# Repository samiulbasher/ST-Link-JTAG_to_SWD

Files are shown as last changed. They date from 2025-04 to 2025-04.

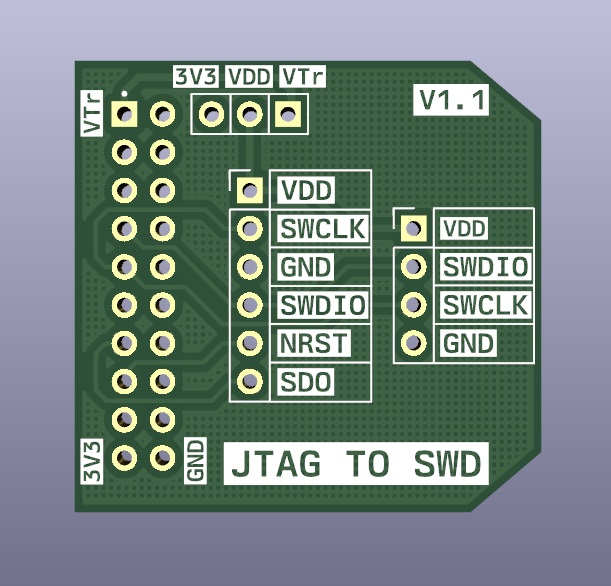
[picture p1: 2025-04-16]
JTAG_to_SWD/circuit/TOP.jpg

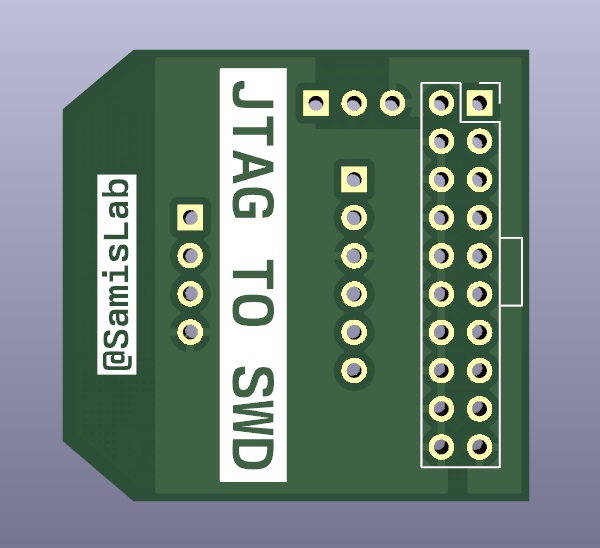
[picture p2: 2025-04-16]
JTAG_to_SWD/circuit/BOTTOM.jpg

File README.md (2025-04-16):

# ST-Link JTAG to SWD Adapter

A simple, compact adapter that converts a legacy ARM 20-pin JTAG/SWD IDC connector to a standard SWD header. Compatible with ST-Link, J-Link, and other JTAG-based programmers.

---

## 🧰 General

This adapter is designed for developers to **simplify the development and debugging process**.

Instead of dealing with messy jumper wires or complex breakout boards, this provides a clean and reliable solution for converting JTAG to SWD—ideal for use with:

- ST-Link  
- J-Link  
- Other generic JTAG programmers

---

## 📌 Features

- **Plug & Play** — No need to look up datasheets or pinouts  
- **Developer-Friendly** — Saves time and reduces frustration  
- **Labeled Pins** — Clear labeling right on the PCB  
- **Reduces Errors** — Focus on your work, not wiring  
- **Compact** — Just 30x31 mm in size (*2-layer PCB*)

---

## 🧾 Applications

- Debugging and programming ARM Cortex-M microcontrollers  
- Quick SWD access for STM32 and other ARM-based chips  
- Works with any 20-pin JTAG header programmer

---

## 📷 Board Images

> Photos of the adapter and panelized PCB:

ST-Link V2 JTAG to SWD Adapter  
ST-Link V3 JTAG to SWD Adapter  
Panelized Board
JTAG to SWD Adapter

---

## 📍 Pin Details

All pin names are printed directly on the PCB.  
Here's a reference for the minimum required connections:

- **4 Pins** (1, 2, 3, 4) — Programming only  
- **6 Pins** (1, 2, 3, 4, 5, 6) — Full debugging + programming

---

## 🔌 Jumper Connection

When using different ST-Link versions:

- **Genuine ST-Link V2 or V3**:  
  Connect `VTarget (VTr)` to `VDD` [target's mcu `VDD`].

- **Clone ST-Link (usually ST-Link V2, e.g., Chinese versions)**:  
  Connect `3V3` to `VDD` [target's mcu `VDD`].

---

## 📦 Specifications

| Attribute | Value |
|---|---|
| Dimensions | 30 mm x 31 mm |
| Connector Type | ARM 20-pin JTAG to SWD Header |
| Programmer Support | ST-Link, J-Link, and others |

---

## ✅ Compatibility

| Programmer | Compatible |
|---|---|
| ST-Link V2 | ✅ |
| ST-Link V3 | ✅ |
| J-Link | ✅ |
| Other JTAG headers | ✅ |

---

---

## 📁 Design Files & Gerber Files

- The `JTAG_to_SWD/` directory contains the original **KiCad project files**.  
  If you’d like to modify or customize the board, you can easily do so using KiCad.

- The `gerber/` directory includes **production-ready files** for PCB manufacturing.

  Inside it, you’ll find a `panel/V1.1/` subfolder — this contains the **panelized version** of the PCB (`JTAG_to_SWD_panel_V1.1.zip`).  
  This file is ready to upload directly to [JLCPCB](https://jlcpcb.com) for manufacturing.

💡 This is a **2-layer PCB**, and each panel contains **6 individual boards**.  
That means for just **$2**, you can get **30 PCBs** produced at JLCPCB!

---

## 📝 License

This project is released under the [MIT License](LICENSE).

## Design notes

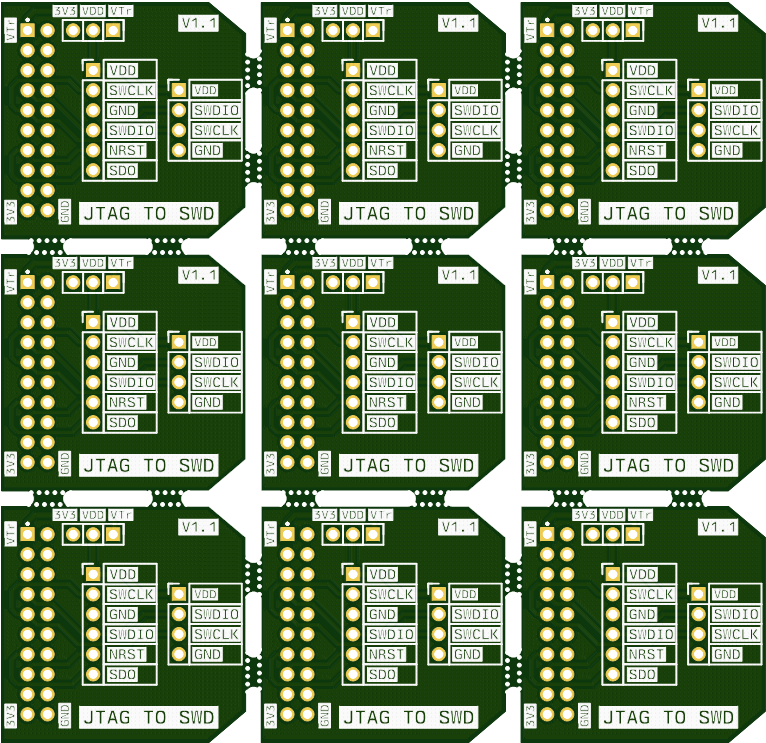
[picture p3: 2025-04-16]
JTAG_to_SWD/gerbers/panel/V1.1/JTAG_to_SWD_panel_V1.1_Combined_Top.png

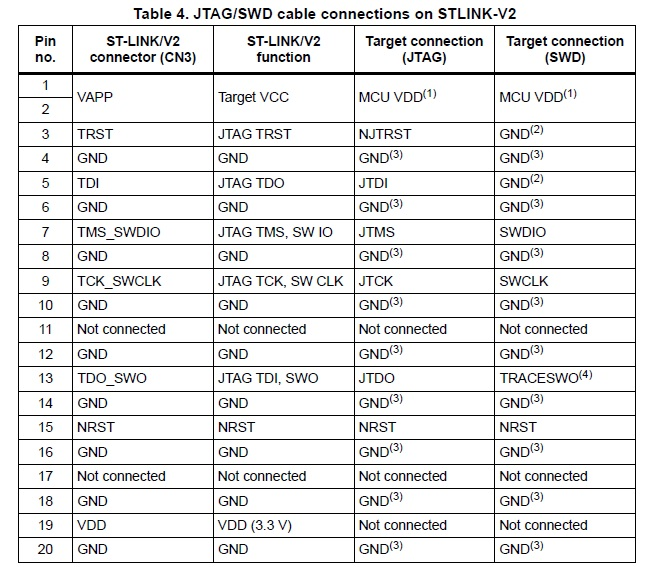
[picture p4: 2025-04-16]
utility/JTAG_STLINK-V2.png

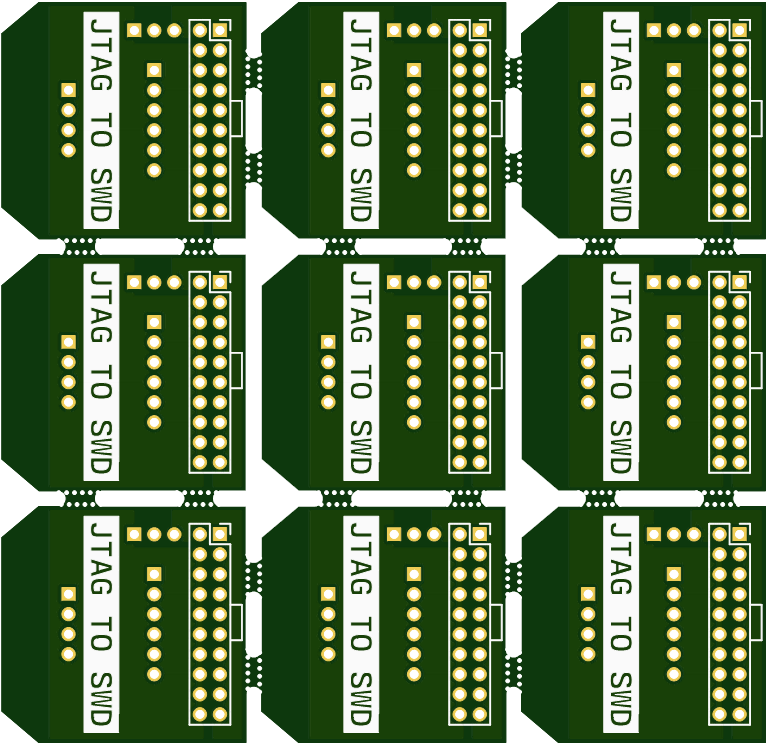
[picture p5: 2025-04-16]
JTAG_to_SWD/gerbers/panel/V1.1/JTAG_to_SWD_panel_V1.1_Combined_Bottom.png

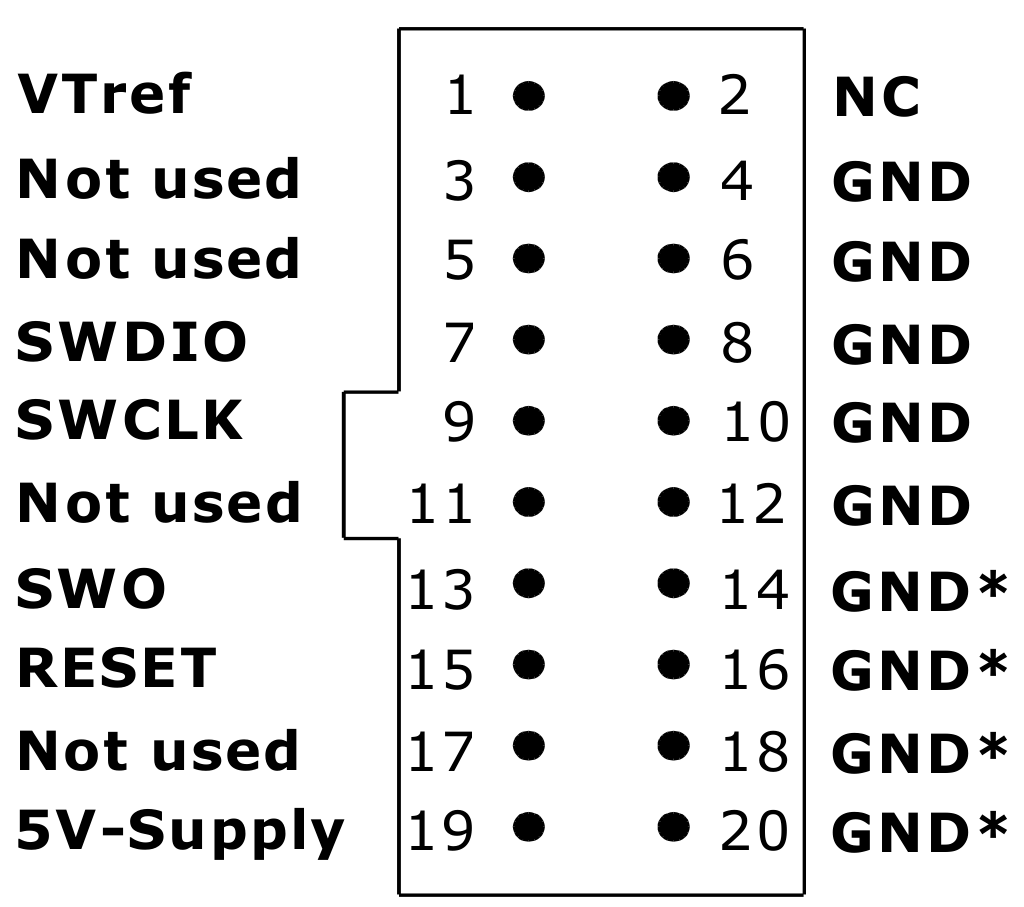
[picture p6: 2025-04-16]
utility/JTAG.png

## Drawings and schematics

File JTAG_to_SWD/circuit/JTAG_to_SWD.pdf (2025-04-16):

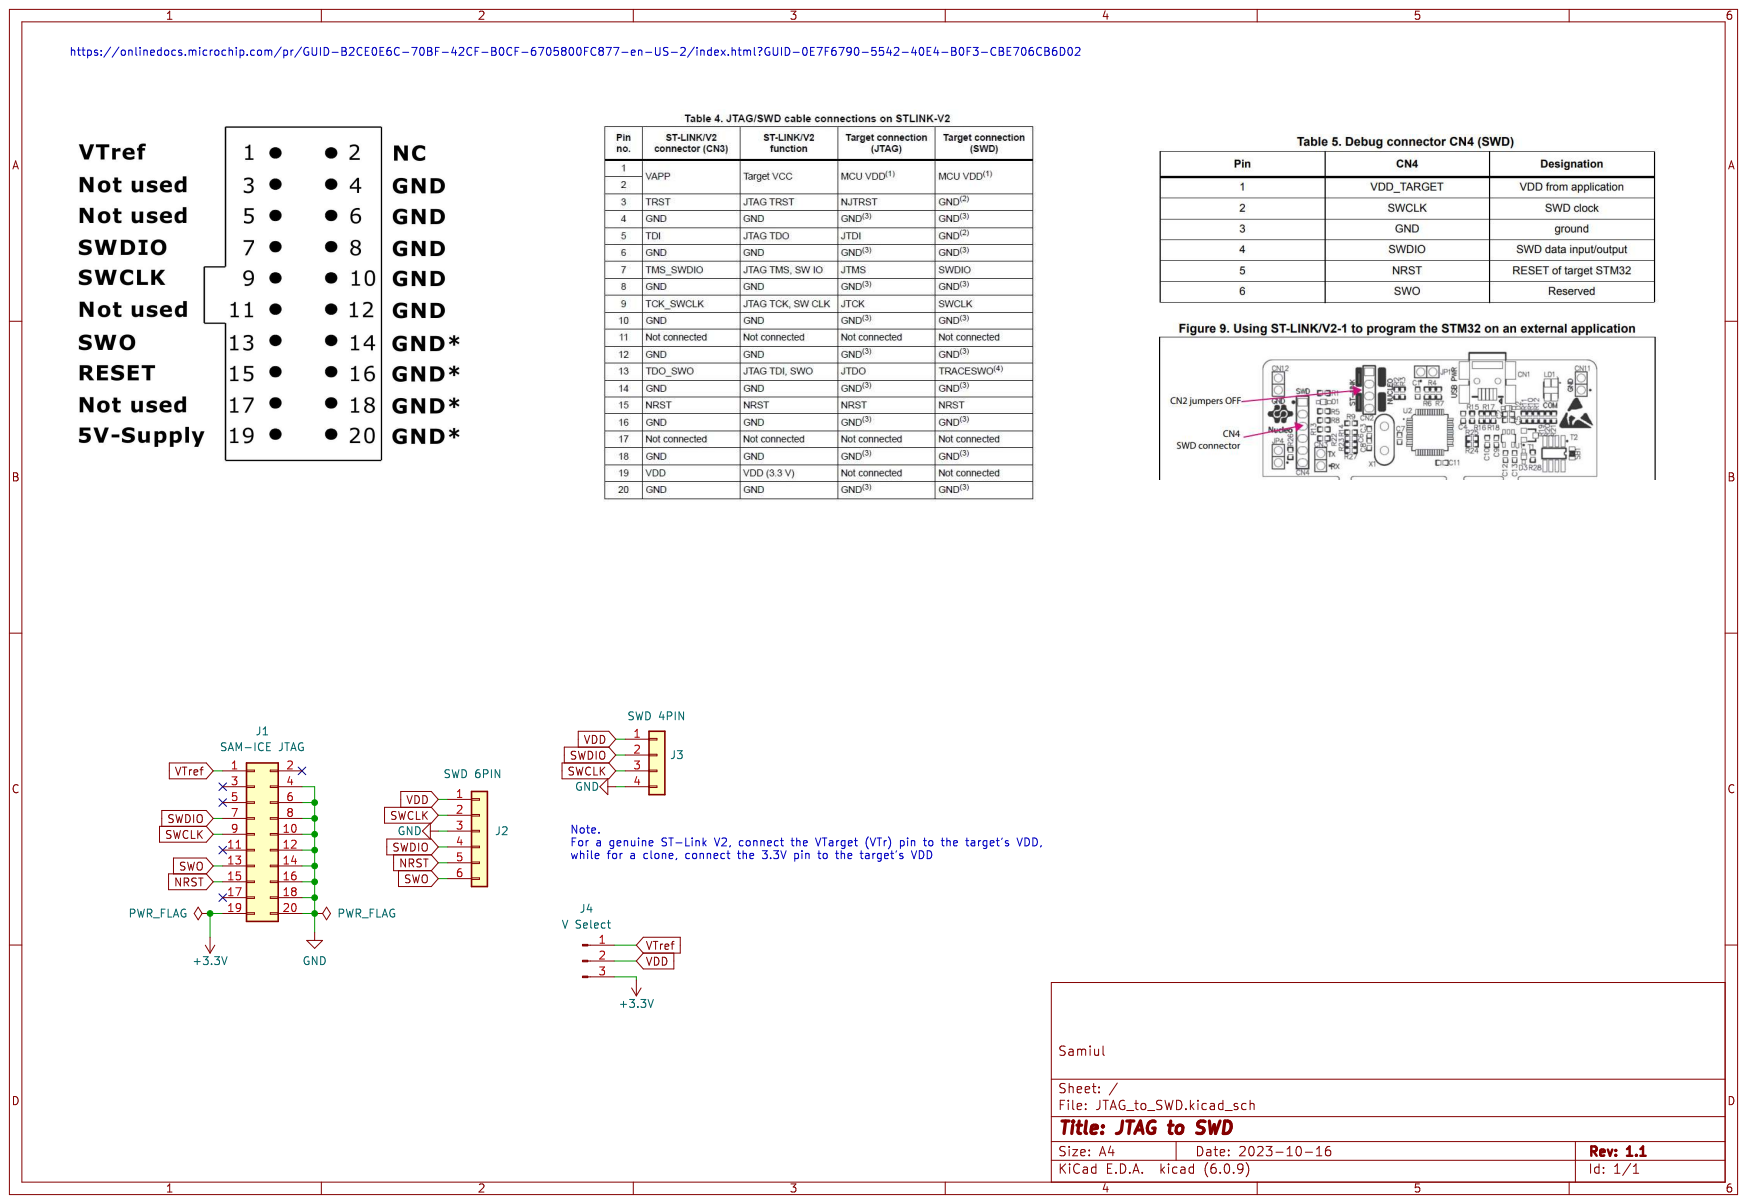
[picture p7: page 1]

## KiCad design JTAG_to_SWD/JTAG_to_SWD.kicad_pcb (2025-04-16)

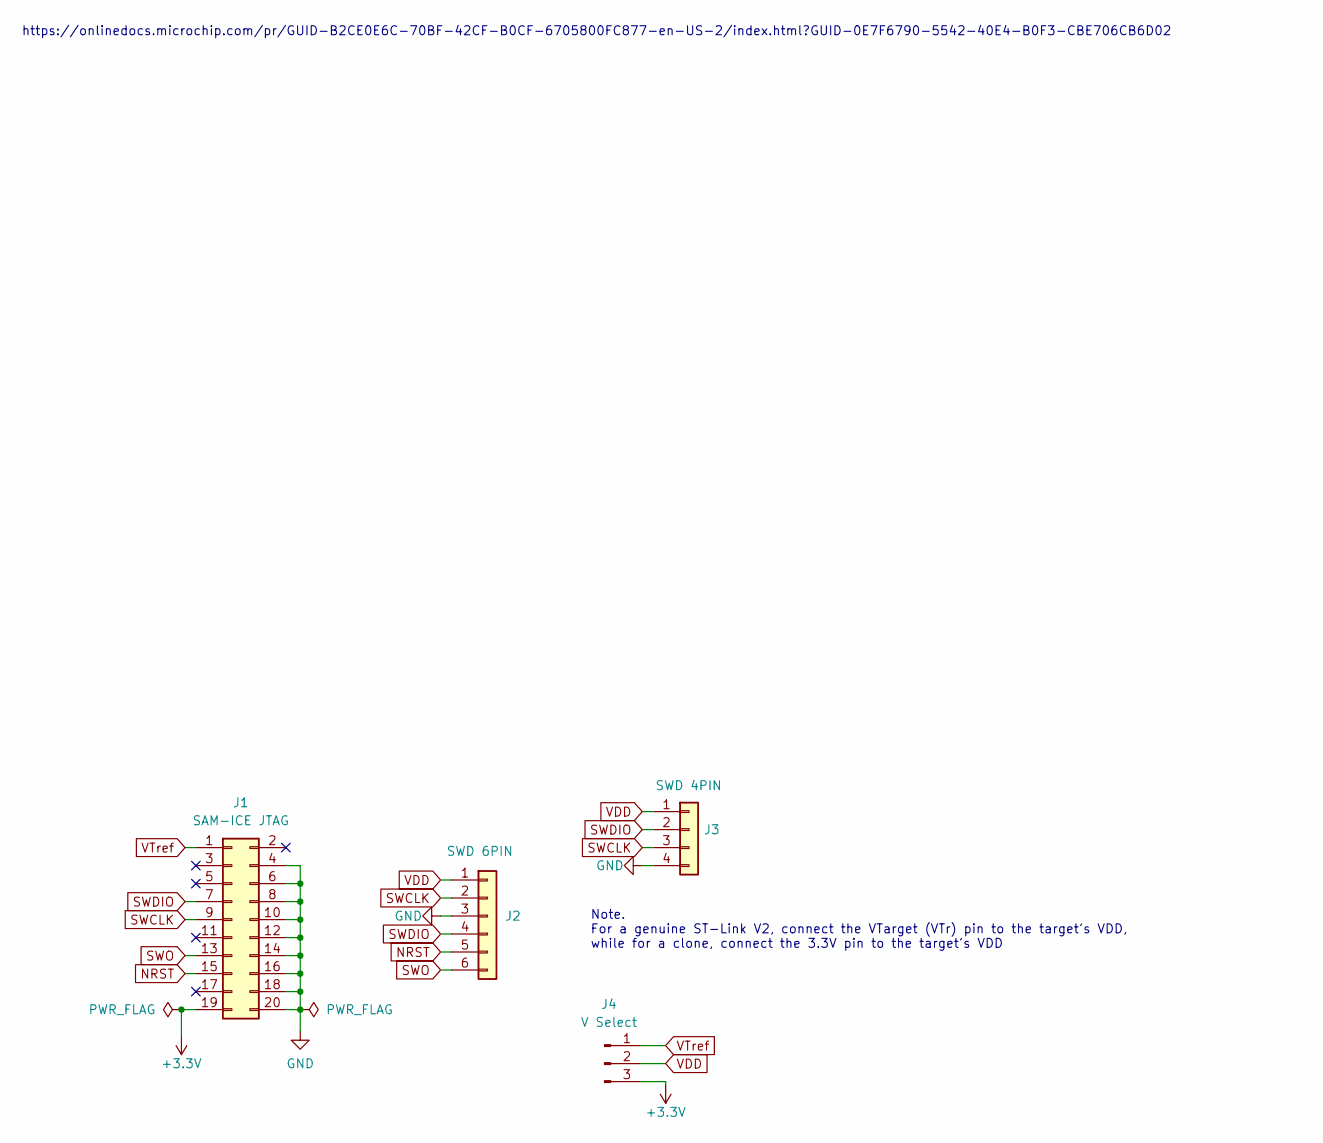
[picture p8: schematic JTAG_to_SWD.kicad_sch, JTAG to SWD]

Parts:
J1: SAM-ICE JTAG; PinSocket_2x10_P2.54mm_Vertical
J2: SWD 6PIN; PinHeader_1x06_P2.54mm_Vertical
J3: SWD 4PIN; PinHeader_1x04_P2.54mm_Vertical
J4: V Select; PinHeader_1x03_P2.54mm_Vertical

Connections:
+3.3V: J1.19, J4.3
GND: J1.4, J1.6, J1.8, J1.10, J1.12, J1.14, J1.16, J1.18, J1.20, J2.3, J3.4
NRST: J1.15, J2.5
SWCLK: J1.9, J2.2, J3.3
SWDIO: J1.7, J2.4, J3.2
SWO: J1.13, J2.6
VDD: J2.1, J3.1, J4.2
VTref: J1.1, J4.1

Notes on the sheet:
https://onlinedocs.microchip.com/pr/GUID-B2CE0E6C-70BF-42CF-B0CF-6705800FC877-en-US-2/index.html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
Note. For a genuine ST-Link V2, connect the VTarget (VTr) pin to the target's VDD, while for a clone, connect the 3.3V pin to the target's VDD

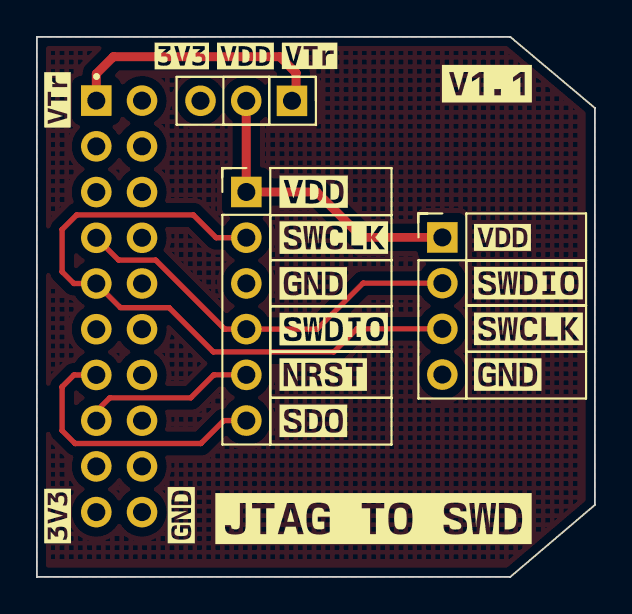
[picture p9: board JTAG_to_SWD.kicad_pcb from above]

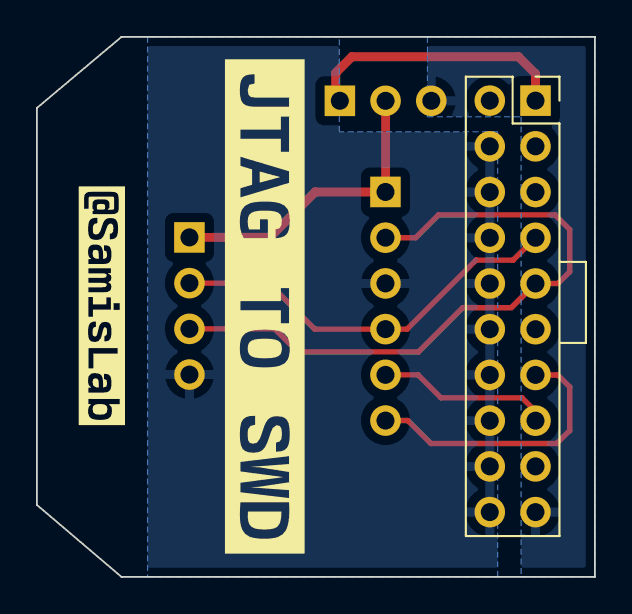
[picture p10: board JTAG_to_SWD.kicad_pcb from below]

Board: 2 copper layers, 31.0 x 30.0 mm, 24 parts (3 on the bottom side), 8 nets.

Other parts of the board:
kibuzzard-652CA4AC: G***; kibuzzard-652CA4AC
kibuzzard-652CAEF1, kibuzzard-652CAEF1#2: G***; kibuzzard-652CAEF1
kibuzzard-652CCC4E: G***; kibuzzard-652CCC4E
kibuzzard-6539E1A4, kibuzzard-6539E1A4#2: G***; kibuzzard-6539E1A4
kibuzzard-6539E4EE: G***; kibuzzard-6539E4EE
kibuzzard-6539E7D0: G***; kibuzzard-6539E7D0
kibuzzard-6539E8AF: G***; kibuzzard-6539E8AF
kibuzzard-6539E8D8: G***; kibuzzard-6539E8D8
kibuzzard-6539E58F: G***; kibuzzard-6539E58F
kibuzzard-6539E59E: G***; kibuzzard-6539E59E
kibuzzard-6539E162: G***; kibuzzard-6539E162
kibuzzard-6539E581: G***; kibuzzard-6539E581
kibuzzard-6539E611: G***; kibuzzard-6539E611
kibuzzard-6539E616: G***; kibuzzard-6539E616
kibuzzard-6539E628: G***; kibuzzard-6539E628
kibuzzard-6539E918: G***; kibuzzard-6539E918
kibuzzard-6539E952: G***; kibuzzard-6539E952
kibuzzard-6656AA27: G***; kibuzzard-6656AA27
